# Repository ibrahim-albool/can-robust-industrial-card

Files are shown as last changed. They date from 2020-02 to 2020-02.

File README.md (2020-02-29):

# can-robust-industrial-card
The Project is robust industrial fully isolated CAN bus node cards, designed to be interfaced with a wood sanding machine PLC, actuators and sensors.  
The project contains two cards, basically the hardware is the same except the option of mounting/removing some opto-couplers in each card. The input card interfaces 46 input sensors, to sense the width of the wood piece in real time, while the output card interfaces 46 output air solenoids, to actuate them in realtime as well.
The cards are dsPIC33EP512MC506 microcontroller based which is 3.3 voltage logic, the voltages are fully isolated among the input, output and controller areas. 
The can message is transmitted to/from CAN buffer directly to the RAM using DMA. CPU then is notified with the data presence to read it, or CPU writes the data to the RAM and notifies the DMA to write it to the CAN bus buffer.

Hardware folder contains the Schematic and Layout designed on Altium designer. 
Software folder contains the input and output cards' software codes built on MPLAB X IDE v3.26, C Compiler Version: XC16 v1.26 .

**The Card:**
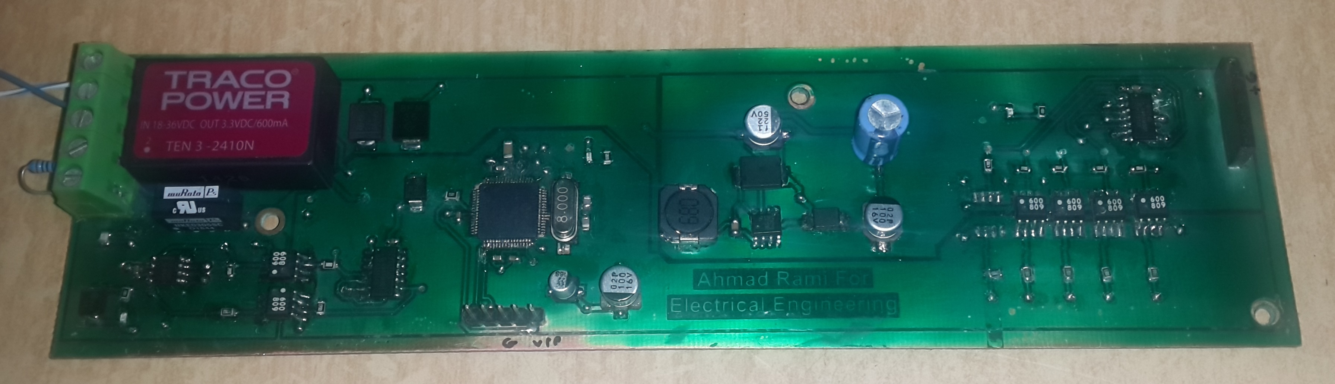
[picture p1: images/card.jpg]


**The Card Powered:**
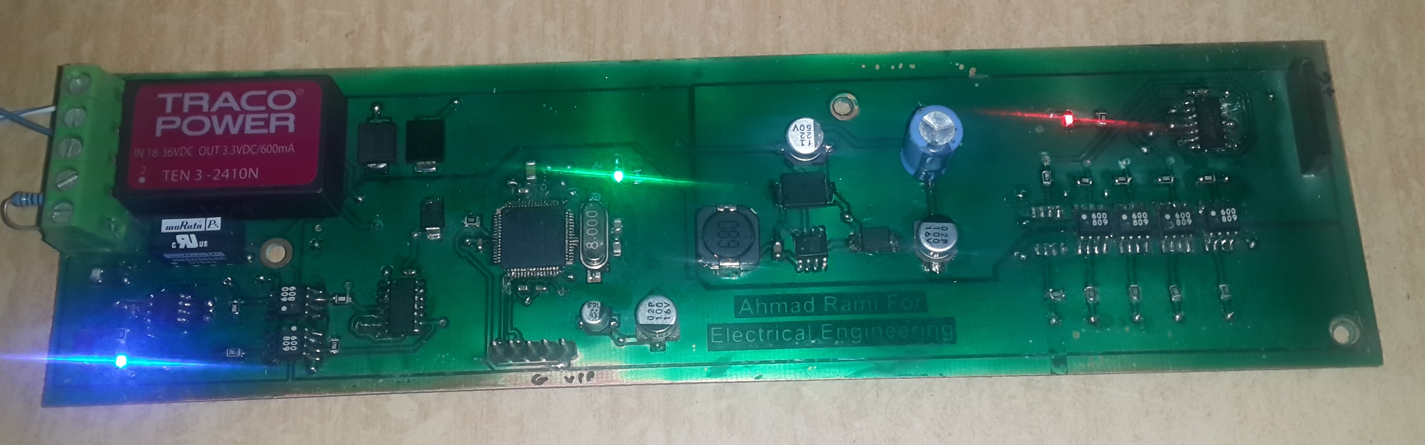
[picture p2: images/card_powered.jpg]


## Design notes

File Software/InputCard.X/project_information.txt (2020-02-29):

<Application Description for Project Goes Here>

Project Owner(s): Ibrahim Albool
Author(s): Ibrahim Albool
Hardware Platform: dsPIC33EP512MC506
Debuggers Used: PICKIT3
Programmers Used: PICKIT3
MPLAB Version: MPLAB X IDE v3.26
C Compiler Version: XC16 v1.26
Final Checksum:

FILES INCLUDED IN THE PROJECT TREE:

system.h - Contains custom oscillator configuration function prototypes,
reset source evaluation function prototypes, and non-peripheral
microcontroller initialization function prototypes.  It also may contain
system level #define macros and variables.  This file is included
by system.c

user.h - Contains parameters and function prototypes used in user.c for user
level functions, for example, InitApp();

configuration_bits.c - Contains device configuration bit macros.  Refer to
the comments in configuration_bits.c for instructions on where to get
information about device configuration bits and their corresponding macros.

interrupts.c - This file contains example stubs for interrupts.  The user would
put the interrupt vectors for their application in interrupts.c.

main.c - This is the main code for the project.  global variables and the
main() function are located in main.c  The user would put their primary program
flow in main.c, and the operation should be contained in main.c with an
infinite loop.

system.c - Contains custom oscillator configuration functions, reset source
evaluation functions, and non-peripheral microcontroller initialization
functions.  Functions in system.c would often be called from main.c during
device initialization.

traps.c - Generally speaking, a user would not modify this file unless
they were having problems resulting in traps.  If the code in this file
is entered, that means there is a critical hardware problem or software bug.
The trap will need evaluated by the user to determine the source
of the problem.  www.microchip.com/codeexamples contains trap example code
which can be used as a reference to help debug traps.

user.c - Custom user algorithms, user peripheral initialization, data
computation functions, and calculation functions would go here.  Prototypes for
user.c would go in user.h.

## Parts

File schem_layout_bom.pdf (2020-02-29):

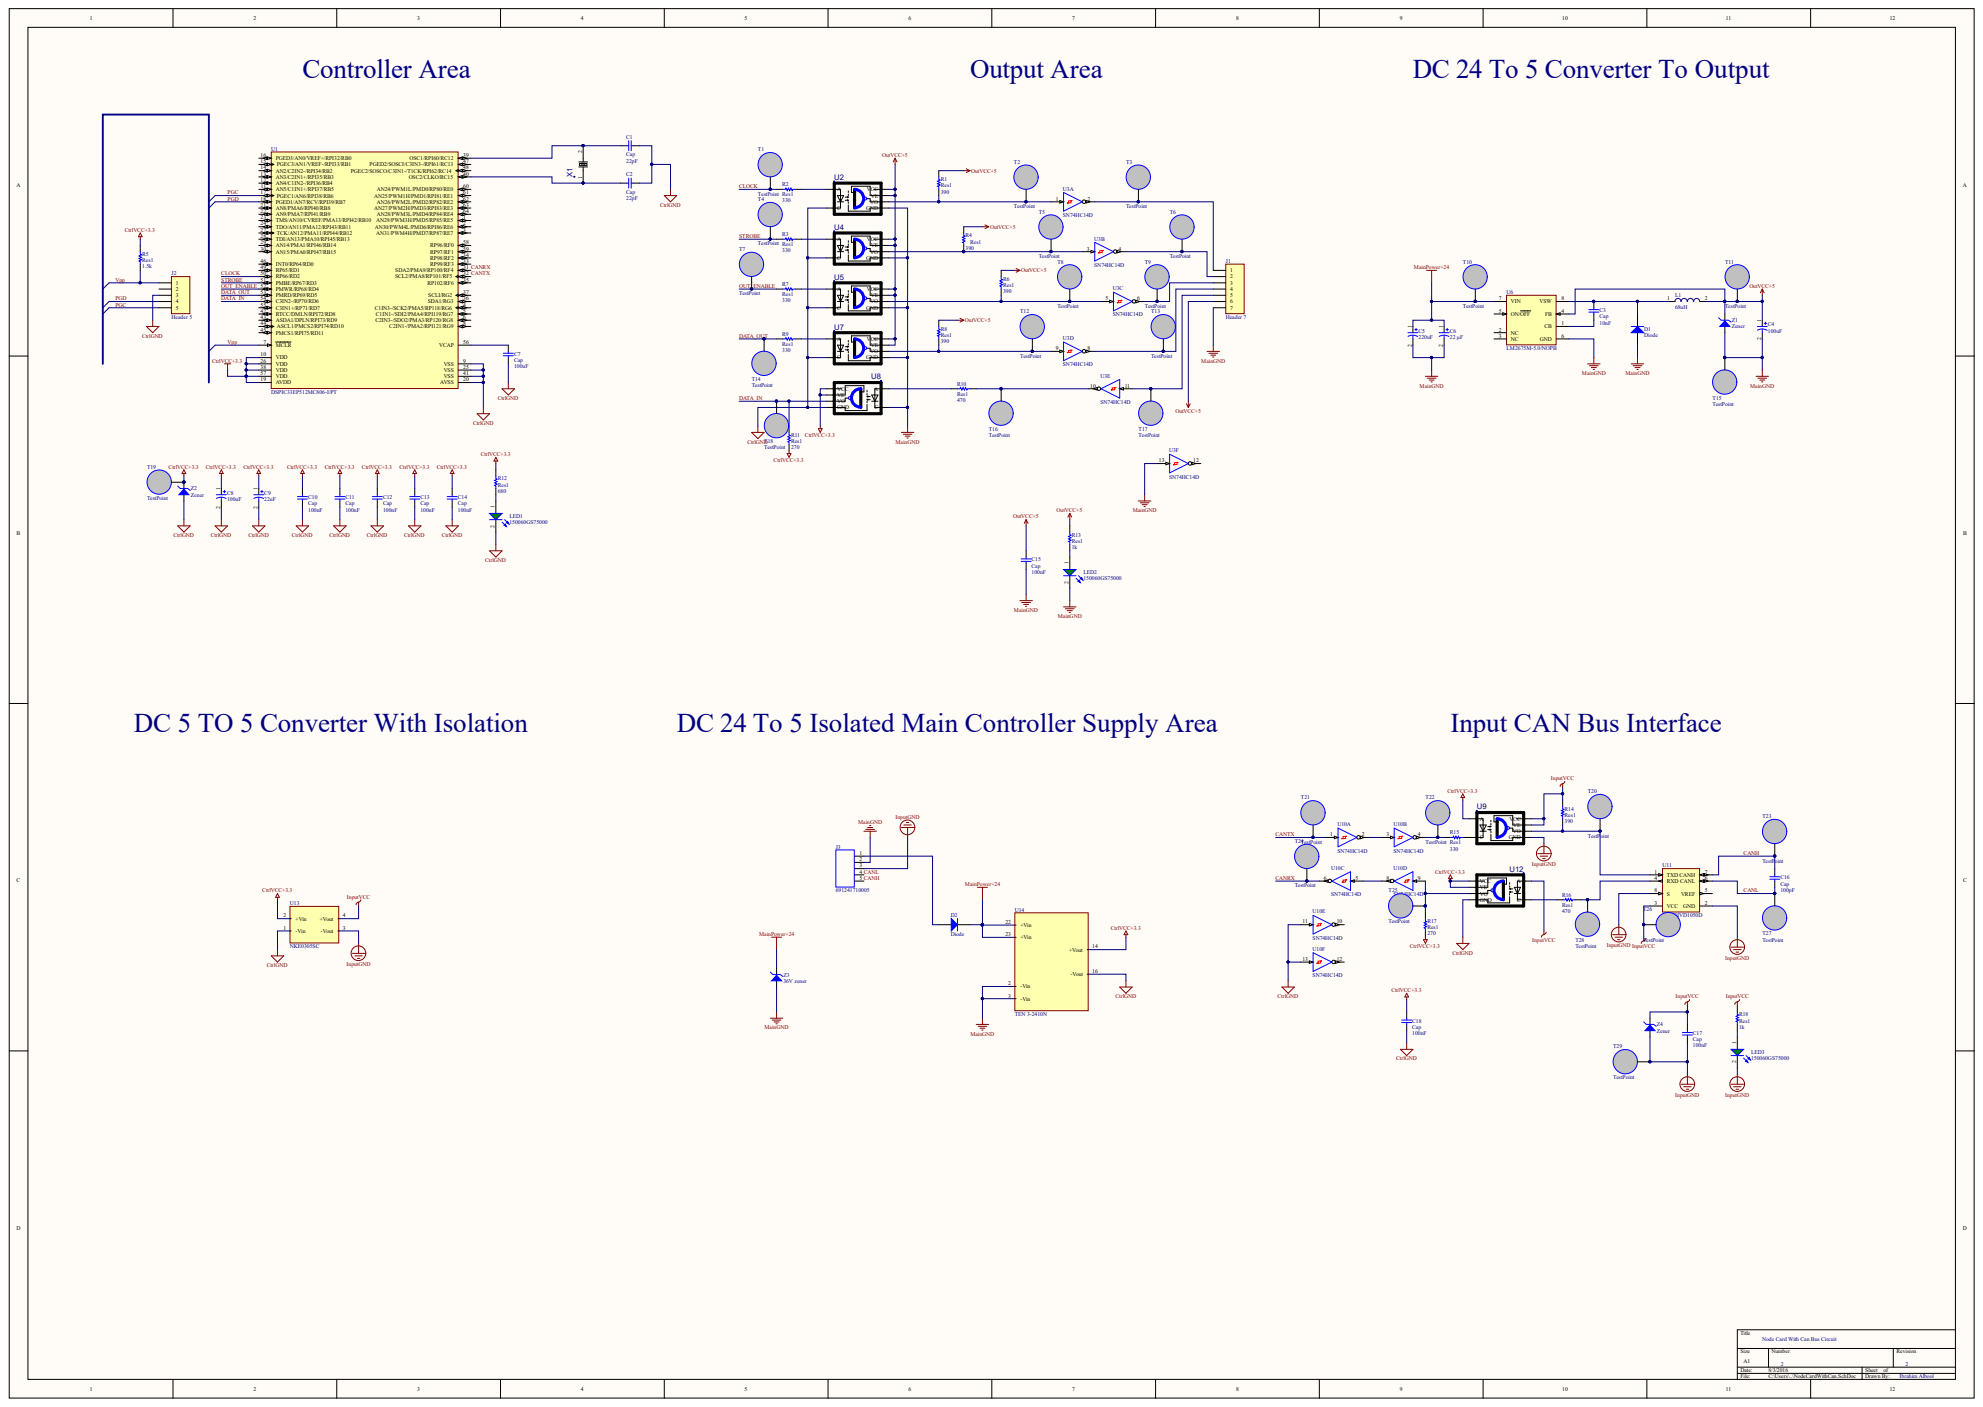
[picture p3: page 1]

Input CAN Bus Interface

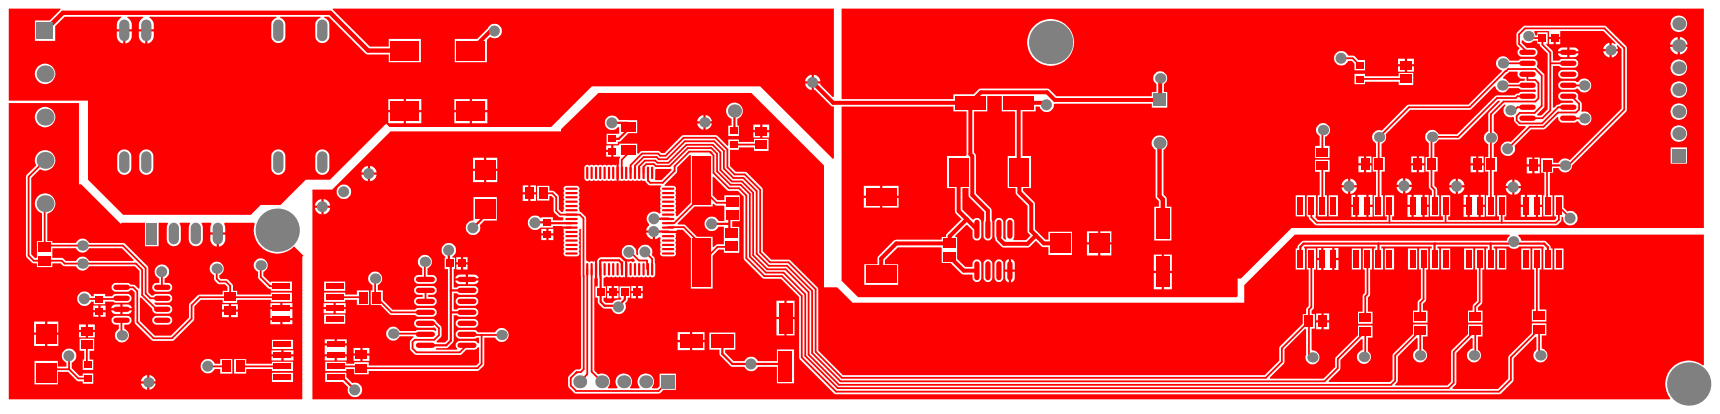
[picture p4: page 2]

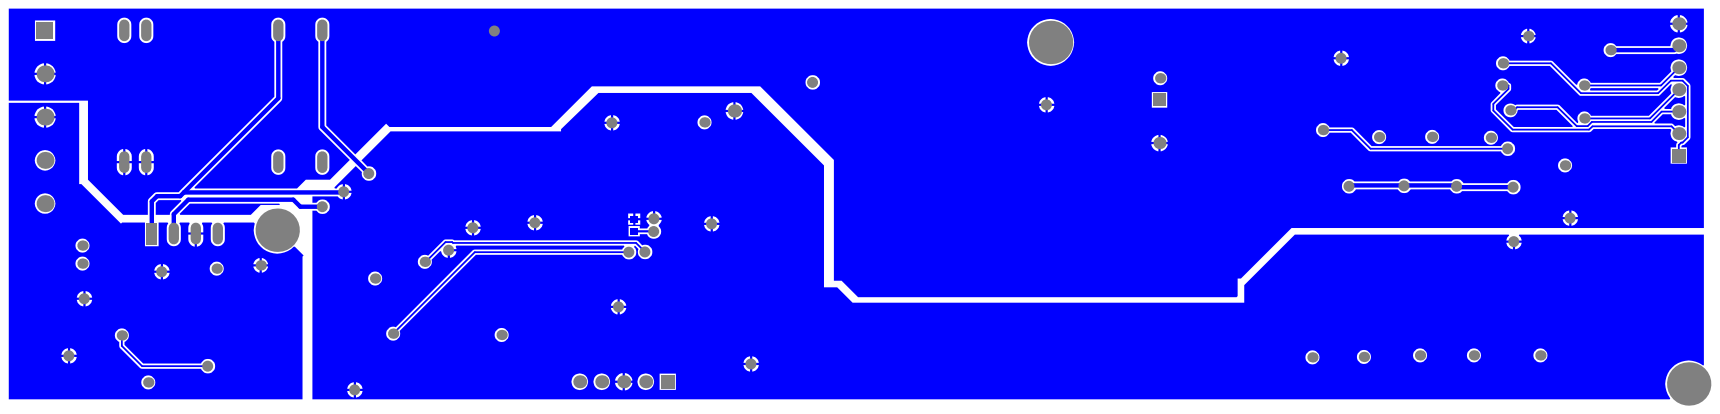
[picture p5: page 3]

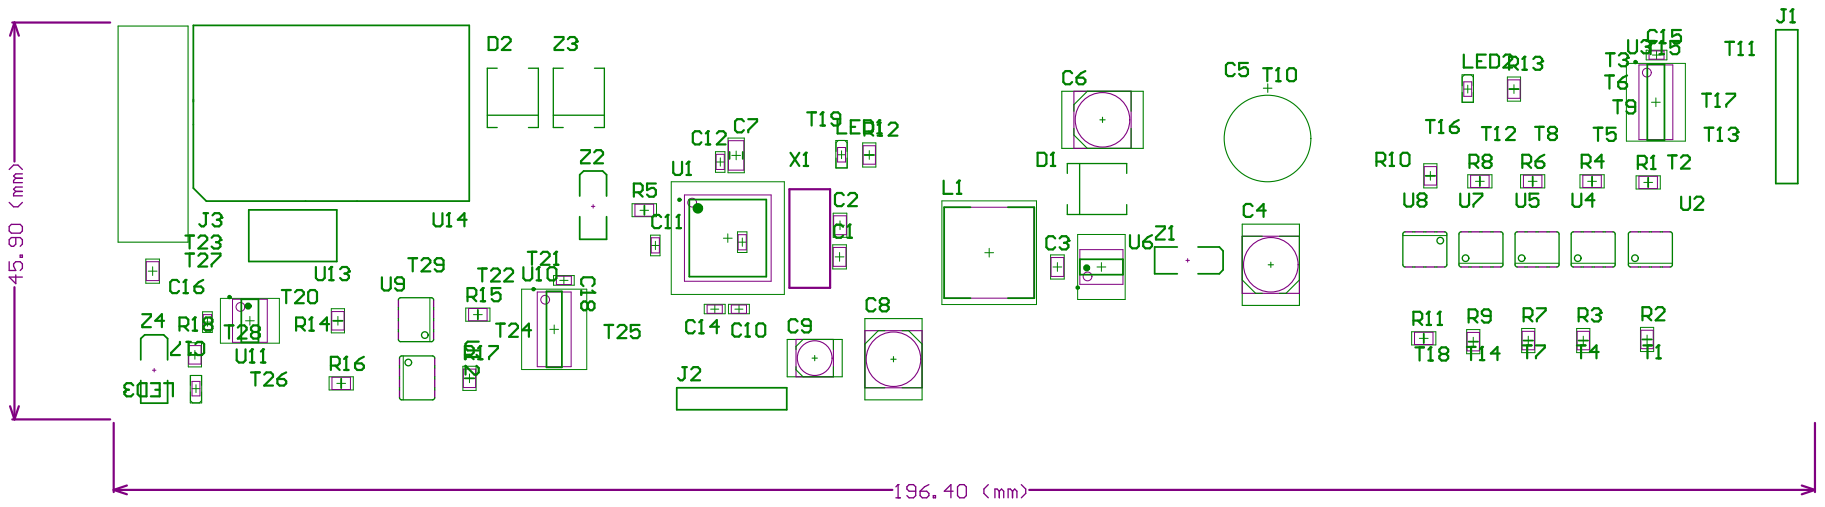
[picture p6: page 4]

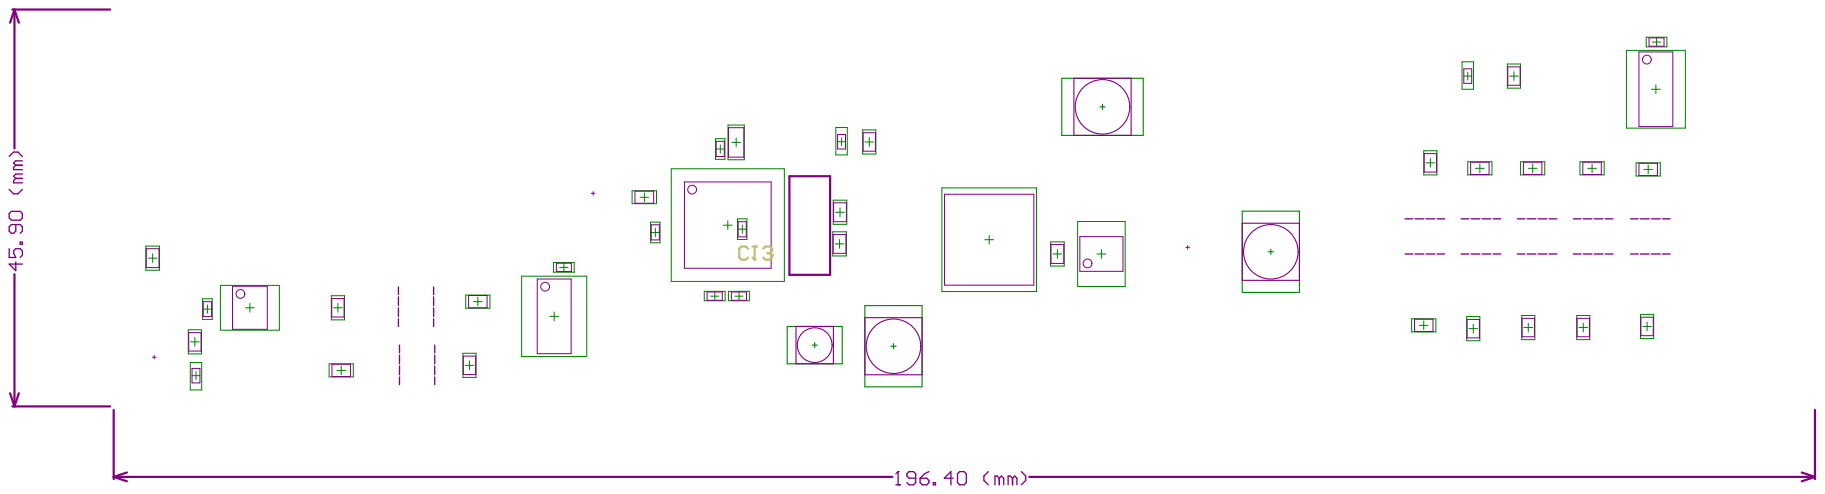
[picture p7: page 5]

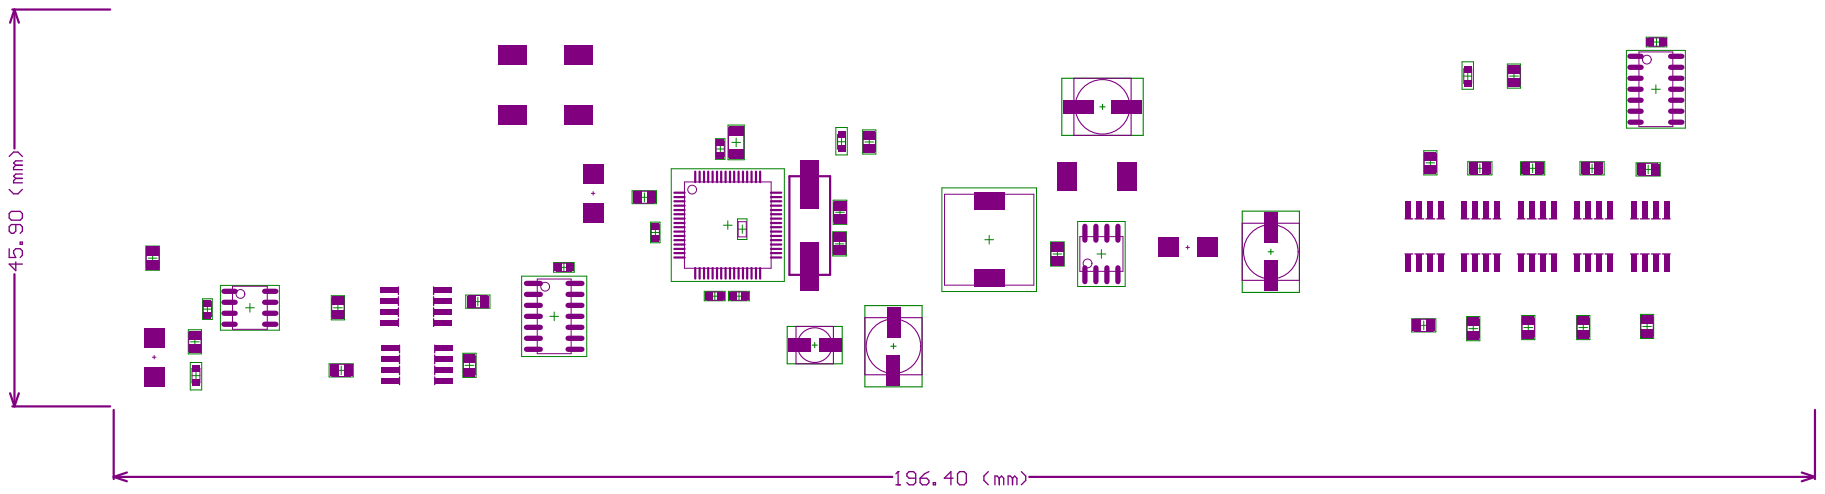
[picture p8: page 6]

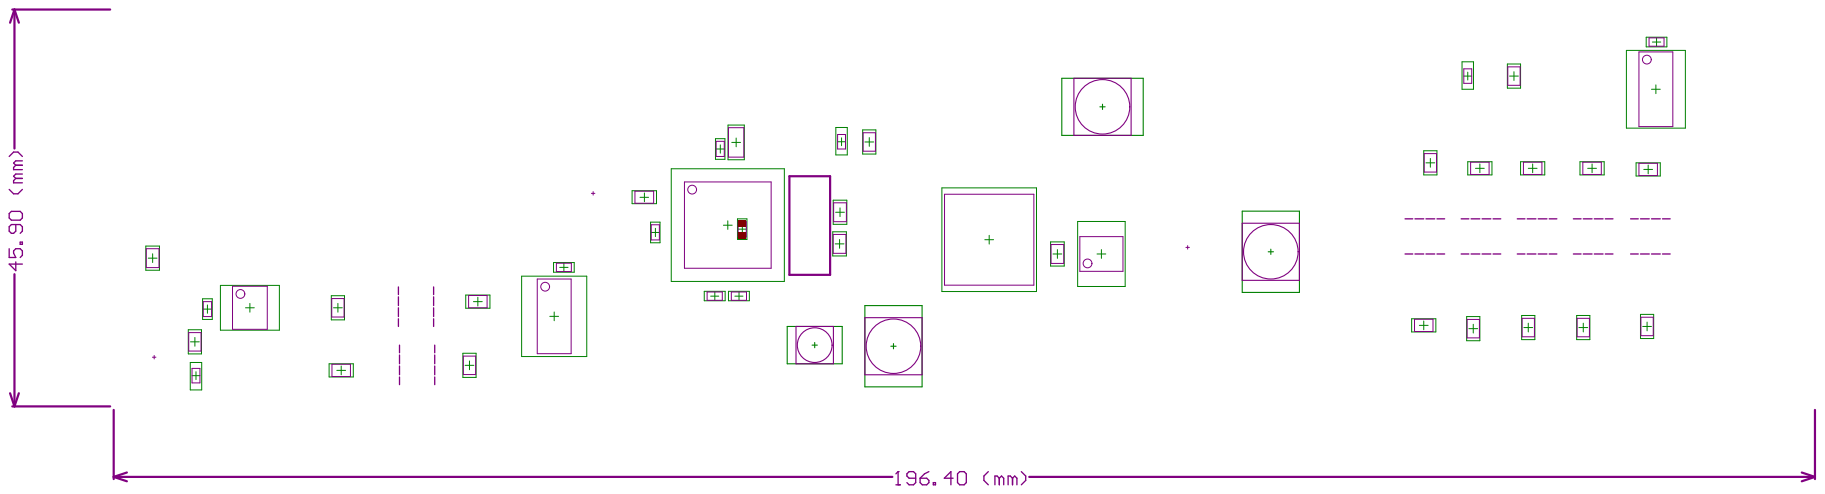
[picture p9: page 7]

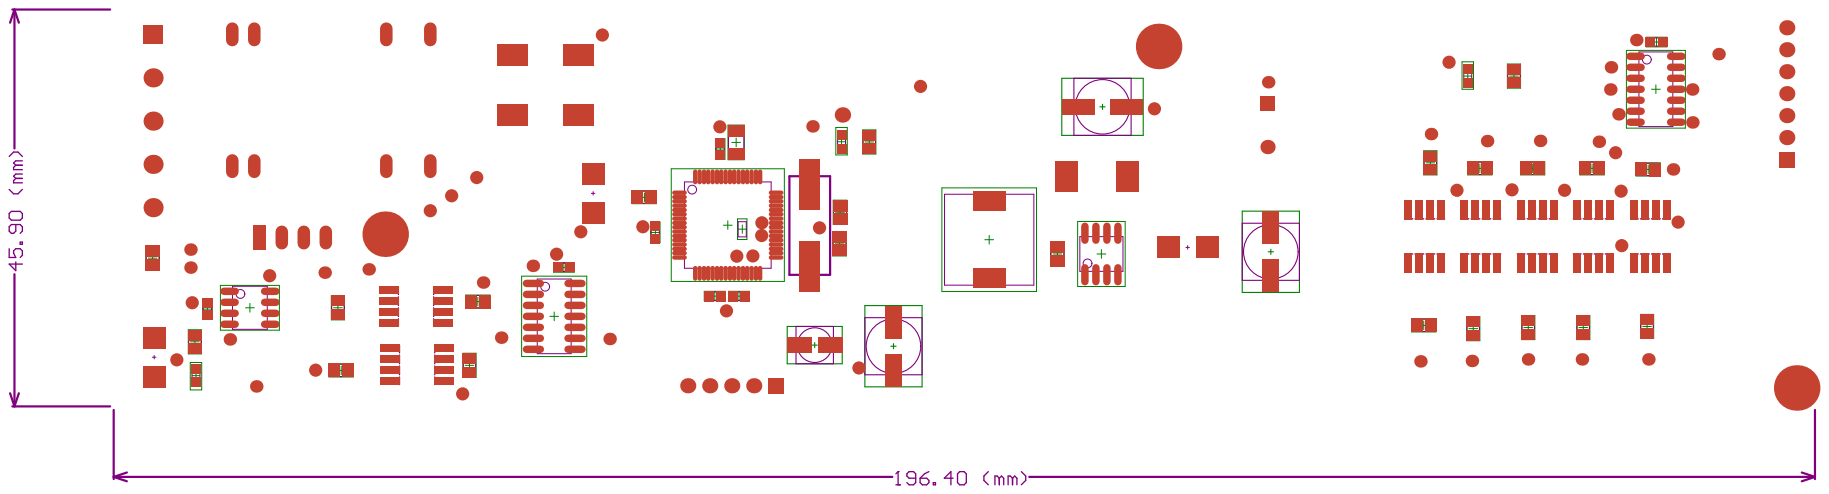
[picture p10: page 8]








Comment | Description | Designator | Footprint | LibRef | Quantity

Cap | Capacitor | C1, C2, C3, C16 | C0805 | Cap | 4
100uF | WCAP-PSLP Aluminum Polymer Capacitors , 22 µF; + / - 20%; 16 V , 6,3 x 5,8, WCAP-PSLP Aluminum Polymer Capacitors , 22 µF; + / -20%; 16V , 6,3 x 5,8 | C4, C8 | WCAP-PSLP 6.3x5.8x2.2 | WCAP-PSLP 6.3x5.8x2.2 875105544003 | 2

220uF | WCAP-PTG5 Aluminum Polymer Capacitors , 1000 µF; + / - 20%; 6,3 V , 10 x 12,5 | C5 | WCAP-PTG5 10x12.5x5x0.6 | WCAP-PTG5 10x12.5x5x0.6 870025175010 | 1

22 µF | WCAP-PSLP Aluminum Polymer Capacitors , 22 µF; + / - 20%; 50 V , 6,3 x 5,8 | C6 | WCAP-PSLP 6.3x5.8x2.2 | WCAP-PSLP 6.3x5.8x2.2 875105544003 | 1

Cap | Capacitor | C7 | C1206 | Cap | 1
22uF | WCAP-PSLP Aluminum Polymer Capacitors , 10 µF; + / - 20%; 10 V , 4 x 5,5 | C9 | WCAP-PSLP 4x5.5x1 | WCAP-PSLP 4x5.5x1 875105240001 | 1

Cap | Capacitor | C10, C11, C12, C13, C14, C15, C17, C18 | 1608[0603] | Cap | 8

Diode | Default Diode | D1, D2 | DO-214AB_Unidirectional | Diode | 2

Header 7 | Header, 7-Pin | J1 | HDR1X7 | Header 7 | 1

Header 5 | Header, 5-Pin | J2 | HDR1X5 | Header 5 | 1

691241710005 | WR-TBL Horizontal Cable Entry With Rising Cage Clamp,Serie 2417 -5.00 mm | J3 | 691241710005 | 691241710005 | 1

68uH | SMD-Shielded Power Inductor WE-PD, L=1.50 µH | L1 | WE-PD 1030 | WE-PD 1030, 7447713015 | 1

150060GS75000 | SMD mono-color Chip LED, WL-SMCW, Green | LED1, LED2, LED3 | LED_0603_Green | WL-SMCW 0603 150060GS75000 | 3

Res1 | Resistor | R1, R2, R3, R4, R5, R6, R7, R8, R9, R10, R11, R12, R13, R14, R15, R16, R17, R18 | 6-0805_L | Res1 | 18

TestPoint | Test Point | T1, T2, T3, T4, T5, T6, T7, T8, T9, T10, T11, T12, T13, T14, T15, T16, T17, T18, T19, T20, T21, T22, T23, T24, T25, T26, T27, T28, T29 | Test Point | Test Point | 29

DSPIC33EP512MC806-I/PT | 16-Bit Microcontroller and Digital Signal Controller with High-Speed PWM, USB and Advanced Analog, 70 MIPS, 53 I/O, EPMP, -40 to 85 degC, 64-pin TQFP (PT64), Tray | U1 | MCHP-TQFP-PT64_N | DSPIC33EP512MC806-I/PT | 1

HCPL0601 | | U2, U4, U5, U7, U8, U9, U12 | SOIC08 | HCPL0601 | 7

SN74HC14D | Hex Schmitt-Trigger Inverter | U3 | D014_L | SN74HC14D | 1

LM2675M-5.0/NOPB | SIMPLE SWITCHER® Power Converter High Efficiency 1A Step-Down Voltage Regulator, 8-pin Narrow SOIC, Pb-Free | U6 | M08A_N | LM2675M-5.0/NOPB | 1

SN74HC14D | Hex Schmitt-Trigger Inverter | U10 | D014_N | SN74HC14D | 1

SN65HVD1050D | High-Speed EMC Optimized CAN Transceiver, 70 mA, 5 V, 40 to 125 degC, 8-pin SOIC (D), Green (RoHS & no Sb/Br) | -U11 | D8_L | SN65HVD1050D | 1

NKE0305SC | muRata 3.3 to 5.0 isolated converter | U13 | NKE0305SC | NKE0305SC | 1

TEN 3-2410N | Traco 24/3.3 isolated converter | U14 | TRACO ISOLATED CONVERTER | TEN 3-2410N | 1

ABLS2-8.000MHZ-D4Y-T | | X1 | XTAL1140X470X330 | ABLS2-8.000MHZ-D4Y-T | 1
Zener | WE-TVSP Power TVS Diode, Unidirectional, 1500 W, 100 VDC | Z1, Z2, Z4 | SMB | WE-TVSP DO-214AB, 824540102 | 3

36V zener | WE-TVSP Power TVS DiodZ3 | | DO -214AB_UnidirectionaW E-TVSP DO-214AB, 824540102 | | 1

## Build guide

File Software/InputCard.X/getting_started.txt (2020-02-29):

This is a general template for the dsPIC33 family of microcontrollers.  It's
purpose is to provide a project shell for users to get started designing their
own applications.  Final qualification and testing of this project is left to
the user.

ADVANCED USER TIP

From the main menu, refer to the Task list by going to Window > Tasks (Ctrl+6).
As long as the task window is not configured to filter out any tasks,
the getting started TODO list embedded in this project will be displayed.

Make sure the 'Show tasks for the main project and for the open projects which
depend on it' option is selected on the left hand side of the Tasks window so
that tasks related to other projects are not active.

HOW TO ADD YOUR OWN CODE TO A TEMPLATE

STEP 1

First install the appropriate C compiler if you have not done so already.

See www.microchip.com/compilers

Next, build this project by clicking the Clean and Build Icon (the hammer and
broom symbol) in the MPLAB X IDE Toolbar.  If this project builds, then you are
ready to make changes for your own application.  If the project does not build,
you need to troubleshoot why the project does not build before moving on.

STEP 2

Embed your device's configuration bits into the code.  Instructions for this
are commented in configuration_bits.c

STEP 3

Unless interrupts are not used in your application, add the interrupt vectors
you intend to use to interrupts.c.  Code stubs are provided in interrupts.c
which you may use an as example.  Make sure that you check the device
datasheet to confirm that the interrupt you are using is present in the device
selected, and check the device .h file for the most up to date list of
interrupt vector mnemonics.

Note that there are two interrupt stubs in interrupts.c.  One is for dsPIC33F,
and the other is for dsPIC33E.  There is no alternate interrupt vector table
for the dsPIC33E family.  

STEP 4

Define system parameters such as the system operating frequency in system.h.

Add system level functions to system.h and system.c.  For example, if
you want a function to determine the reset source of the device to know if you
need to backup data, do an oscillator switch, enter a low power mode, etc...
these types of functions may be added to system.c and prototypes can go in
system.h.

STEP 5

Add user level functions to user.h and user.c.  User level functions are
functions that initialize I/O, initialize user peripherals like the ADC,
compute user algorithms, perform calculations on sampled user data, and so on.
User function prototypes and macros may be placed in user.h, and user
functions themselves may go in user.c

STEP 6

Add code to main.c on the line that says <INSERT USER APPLICATION CODE HERE>.
For example, here you would call functions in user.c or system.c, or possibly
setup your own state machine or primary code loop.

Global variables may be added to main.c as well.  As a general practice, macros
and prototypes may go in header files, but variable declarations should not
go in .h files.  Variable declarations should be placed in .c files.

STEP 7

Design the rest of your application.  Add new files to the application, and
test the finished product.

STEP 8

Document what the project does and include other project information in
project_information.txt.

KNOWN ISSUES

For some dsPIC 'GS' devices, you may get a build error like this:

traps.c: In function '_DMACError':
traps.c:103: error: 'INTCON1BITS' has no member named 'DMACERR'
traps.c: In function '_AltDMACError':
traps.c:140: error: 'INTCON1BITS' has no member named 'DMACERR'
traps.c: At top level:
traps.c:157: warning: Invalid interrupt vector names for device '33FJ06GS101'
are:
        _DMACError
        _AltDMACError
        _DMACError
        _AltDMACError

The reason is that the __HAS_DMA__ macro is defined for these devices but it
should not be (at least in XC 1.10 and C30 3.31).  To fix the problem simply
delete the offending interrupts (they are not available anyway.

This issue is already logged and may be fixed in the future.  

Tracking # CAEDTISS-1011

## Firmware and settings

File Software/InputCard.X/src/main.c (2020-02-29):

/**********************************************************************
* © 2005 Microchip Technology Inc.
*
* FileName:        main.c
* Dependencies:    Header (.h) files if applicable, see below
* Processor:       dsPIC33Fxxxx
* Compiler:        MPLAB® C30 v3.00 or higher
*
* SOFTWARE LICENSE AGREEMENT:
* Microchip Technology Incorporated ("Microchip") retains all ownership and 
* intellectual property rights in the code accompanying this message and in all 
* derivatives hereto.  You may use this code, and any derivatives created by 
* any person or entity by or on your behalf, exclusively with Microchip's
* proprietary products.  Your acceptance and/or use of this code constitutes 
* agreement to the terms and conditions of this notice.
*
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
* YOU ACKNOWLEDGE AND AGREE THAT, IN NO EVENT, SHALL MICROCHIP BE LIABLE, WHETHER 
* IN CONTRACT, WARRANTY, TORT (INCLUDING NEGLIGENCE OR BREACH OF STATUTORY DUTY), 
* STRICT LIABILITY, INDEMNITY, CONTRIBUTION, OR OTHERWISE, FOR ANY INDIRECT, SPECIAL, 
* PUNITIVE, EXEMPLARY, INCIDENTAL OR CONSEQUENTIAL LOSS, DAMAGE, FOR COST OR EXPENSE OF 
* ANY KIND WHATSOEVER RELATED TO THE CODE, HOWSOEVER CAUSED, EVEN IF MICROCHIP HAS BEEN 
* ADVISED OF THE POSSIBILITY OR THE DAMAGES ARE FORESEEABLE.  TO THE FULLEST EXTENT 
* ALLOWABLE BY LAW, MICROCHIP'S TOTAL LIABILITY ON ALL CLAIMS IN ANY WAY RELATED TO 
* THIS CODE, SHALL NOT EXCEED THE PRICE YOU PAID DIRECTLY TO MICROCHIP SPECIFICALLY TO 
* HAVE THIS CODE DEVELOPED.
*
* You agree that you are solely responsible for testing the code and 
* determining its suitability.  Microchip has no obligation to modify, test, 
* certify, or support the code.
*
* REVISION HISTORY:
*~~~~~~~~~~~~~~~~~~~~~~~~~~~~~~~~~~~~~~~~~~~~~~~~~~~~~~~~~~~~~~~~~~~~~~~~~~~~~~~~~~~~~~~~~~~~~~~~~
* Author          	Date      Comments on this revision
*~~~~~~~~~~~~~~~~~~~~~~~~~~~~~~~~~~~~~~~~~~~~~~~~~~~~~~~~~~~~~~~~~~~~~~~~~~~~~~~~~~~~~~~~~~~~~~~~~
* Vinaya Skanda 	10/18/06  First release of source file
* Vinaya Skanda		07/25/07  Updates from Joe Supinsky and Jatinder Gharoo incorporated
*~~~~~~~~~~~~~~~~~~~~~~~~~~~~~~~~~~~~~~~~~~~~~~~~~~~~~~~~~~~~~~~~~~~~~~~~~~~~~~~~~~~~~~~~~~~~~~~~~
*
* ADDITIONAL NOTES:
* This code is tested on CANNodeCard Version2 board with B&R 2003 PLC.
* The device used is dsPIC33EP512MC506 controller 
*
* The Processor starts with the External Crystal without PLL enabled and then the Clock is switched to PLL Mode.
*************************************************************************************************/

/* Device header file */
#if defined(__XC16__)
    #include <xc.h>
#elif defined(__C30__)
    #if defined(__dsPIC33E__)
    	#include <p33Exxxx.h>
    #elif defined(__dsPIC33F__)
    	#include <p33Fxxxx.h>
    #endif
#endif


#include <stdint.h>        /* Includes uint16_t definition                    */
#include <stdbool.h>       /* Includes true/false definition                  */

#include "../h/ECAN1Config.h"
#include "../h/user.h"
#include "../h/system.h"
#include "../h/common.h"

//  Macros for Configuration Fuse Registers 

#pragma config GWRP = OFF           // General Segment Write-Protect bit (General Segment may be written)
//#pragma config GSS = OFF            // General Segment Code-Protect bit (General Segment Code protect is disabled)
//#pragma config GSSK = OFF           // General Segment Key bits (General Segment Write Protection and Code Protection is Disabled)

// FOSCSEL
#pragma config FNOSC = FRC          // Initial Oscillator Source Selection Bits (Internal Fast RC (FRC))
#pragma config IESO = OFF           // Two-speed Oscillator Start-up Enable bit (Start up with user-selected oscillator source)

// FOSC
#pragma config POSCMD = XT          // Primary Oscillator Mode Select bits (XT Crystal Oscillator Mode)
#pragma config OSCIOFNC = OFF       // OSC2 Pin Function bit (OSC2 is clock output)
#pragma config IOL1WAY = OFF        // Peripheral pin select configuration (Allow multiple reconfigurations)
#pragma config FCKSM = CSECMD       // Clock Switching Mode bits (Clock switching is enabled,Fail-safe Clock Monitor is disabled)

// FWDT
#pragma config WDTPOST = PS32768    // Watchdog Timer Postscaler Bits (1:32,768)
#pragma config WDTPRE = PR128       // Watchdog Timer Prescaler bit (1:128)
#pragma config PLLKEN = ON          // PLL Lock Wait Enable bit (Clock switch to PLL source will wait until the PLL lock signal is valid.)
#pragma config WINDIS = OFF         // Watchdog Timer Window Enable bit (Watchdog Timer in Non-Window mode)
#pragma config FWDTEN = OFF         // Watchdog Timer Enable bit (Watchdog timer enabled/disabled by user software)

// FPOR
//#pragma config FPWRT = PWR128       // Power-on Reset Timer Value Select bits (128ms)
//#pragma config BOREN = ON           // Brown-out Reset (BOR) Detection Enable bit (BOR is enabled)
#pragma config ALTI2C1 = OFF        // Alternate I2C pins for I2C1 (SDA1/SCK1 pins are selected as the I/O pins for I2C1)
#pragma config ALTI2C2 = OFF        // Alternate I2C pins for I2C2 (SDA2/SCK2 pins are selected as the I/O pins for I2C2)

// FICD
#pragma config ICS = PGD1           // ICD Communication Channel Select bits (Communicate on PGEC1 and PGED1)
//#pragma config RSTPRI = PF          // Reset Target Vector Select bit (Device will obtain reset instruction from Primary flash)
#pragma config JTAGEN = OFF         // JTAG Enable bit (JTAG is disabled)



// Define ECAN Message Buffers
__eds__ ECAN1MSGBUF ecan1msgBuf __attribute__((eds,aligned(ECAN1_MSG_BUF_LENGTH*16)));

// Define Global Variables
unsigned char dataAcknowledgmentWaiting=0; /* Data is sent and acknowledgment signal is being waiteds.*/

unsigned char manualMessageTrigger=0; /* Send the data manually even it is not changed, when connection message is sent*/

unsigned char doSingleShoot; /* Starts the counting for sending a single message */

// Prototype Declaration

int main(void)
{

/* Configure Oscillator Clock Source 	*/
//    TRISCbits.TRISC6=0;
//    while(1){
//        clock=1;
//        clock=0;
//    }

	configureOscillator();
/* Clear Interrupt Flags 				*/
	clearIntrflags();


/* ECAN1 Initialisation 		
   Configure DMA Channel 0 for ECAN1 Transmit
   Configure DMA Channel 2 for ECAN1 Receive */
	ecan1Init();
	dma0init();	
	dma2init();

/* Enable DMA related ECAN1 Interrupt 	*/			
    IEC0bits.DMA0IE=1;
    IEC1bits.DMA2IE=1;
    
//    IEC2bits.C1IE = 1;
//	C1INTEbits.TBIE = 1;	
//	C1INTEbits.RBIE = 1;


 
/* Write messages to the buffers			*/

    ecan1WriteConnectionAcknowldgment();
    ecan1WriteDataTemplate();
    ecan1WriteErrorMessage();
	C1TR01CONbits.TXREQ0=0;
	C1TR01CONbits.TXREQ1=0;
	C1TR23CONbits.TXREQ2=0;
	C1TR23CONbits.TXREQ3=0;
	C1TR45CONbits.TXREQ4=0;
	C1TR45CONbits.TXREQ5=0;


    
/* IO TRIS and LAT registers initialization*/
    initIOs();
   
    
/* Loop infinitely */
    
    while (1){
        int i=5500;
        while (i-->0)
            ;
        getInPoints();
        if(doSingleShoot)
            startCountingForMessageSend(0);
    }
	
}
